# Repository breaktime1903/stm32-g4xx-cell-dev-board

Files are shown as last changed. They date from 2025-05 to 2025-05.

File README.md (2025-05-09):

# STM32G4xx Cell DevBoard开发板

一时兴起无聊做的STM32G4开发板（因为G474/G431两个芯片pin2pin兼容所以在上面加了个丝印区分，应该是通用的吧），称之为Cell是因为这玩意确实比较小巧，目前功能如下：

- 25MHz HSE晶振，32.768KHz LSE晶振
- USB Type-C接口（占用PA11，PA12）
- 0.91寸SSD1306 128x32 OLED显示屏，OLED使用PB8（SCL），PB9（SDA）作为引脚，而PB8与BOOT0复用，使用前需要在STM32CubeProgrammer修改Option Bytes
- TPS54302降压供电，最高支持28V输入电压，最大电流为2A（受制于电感

后面应该会基于这个板子设计底板。

### 目前已经打样验证，可放心使用

OLED

两块板子

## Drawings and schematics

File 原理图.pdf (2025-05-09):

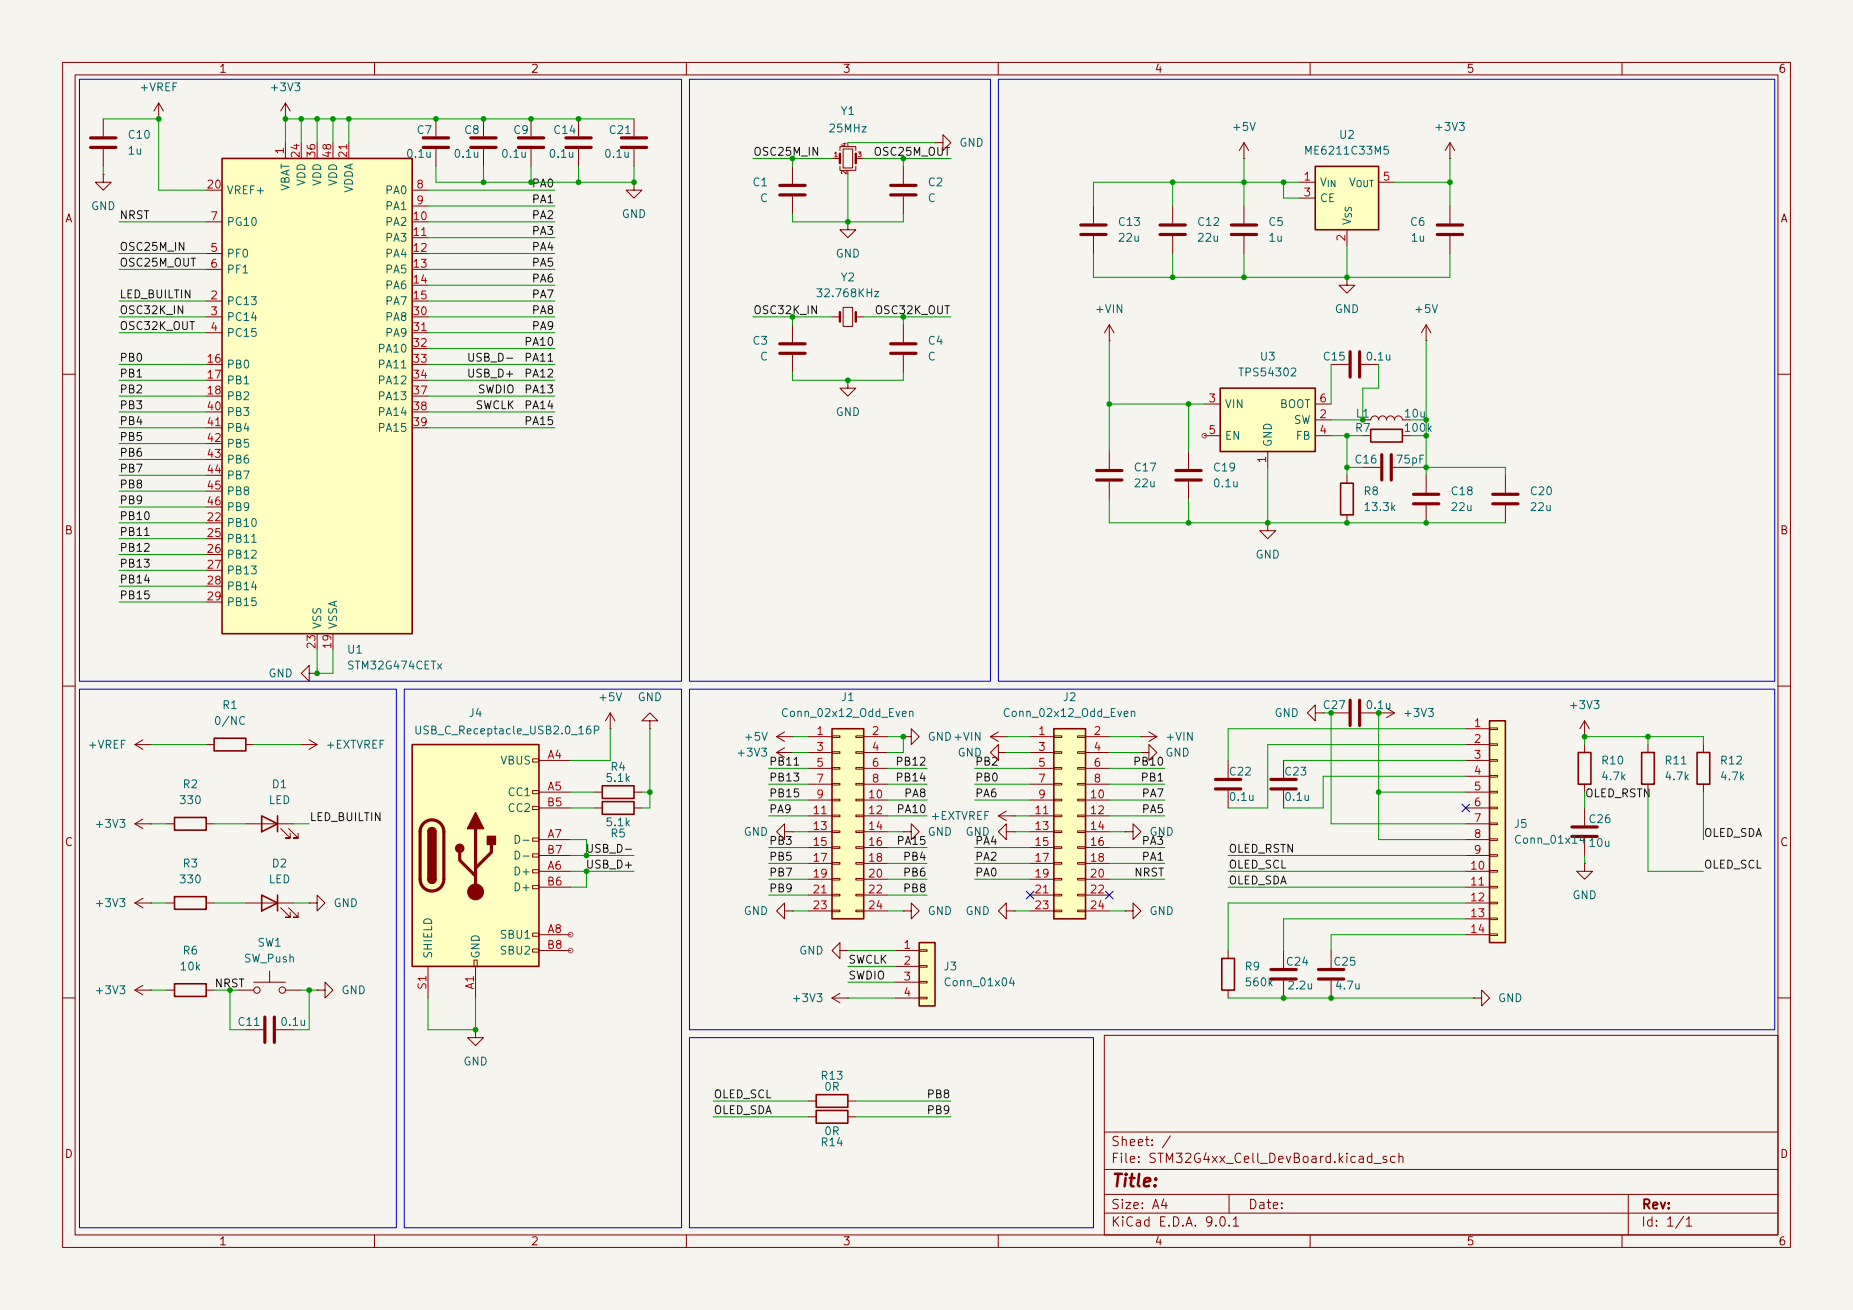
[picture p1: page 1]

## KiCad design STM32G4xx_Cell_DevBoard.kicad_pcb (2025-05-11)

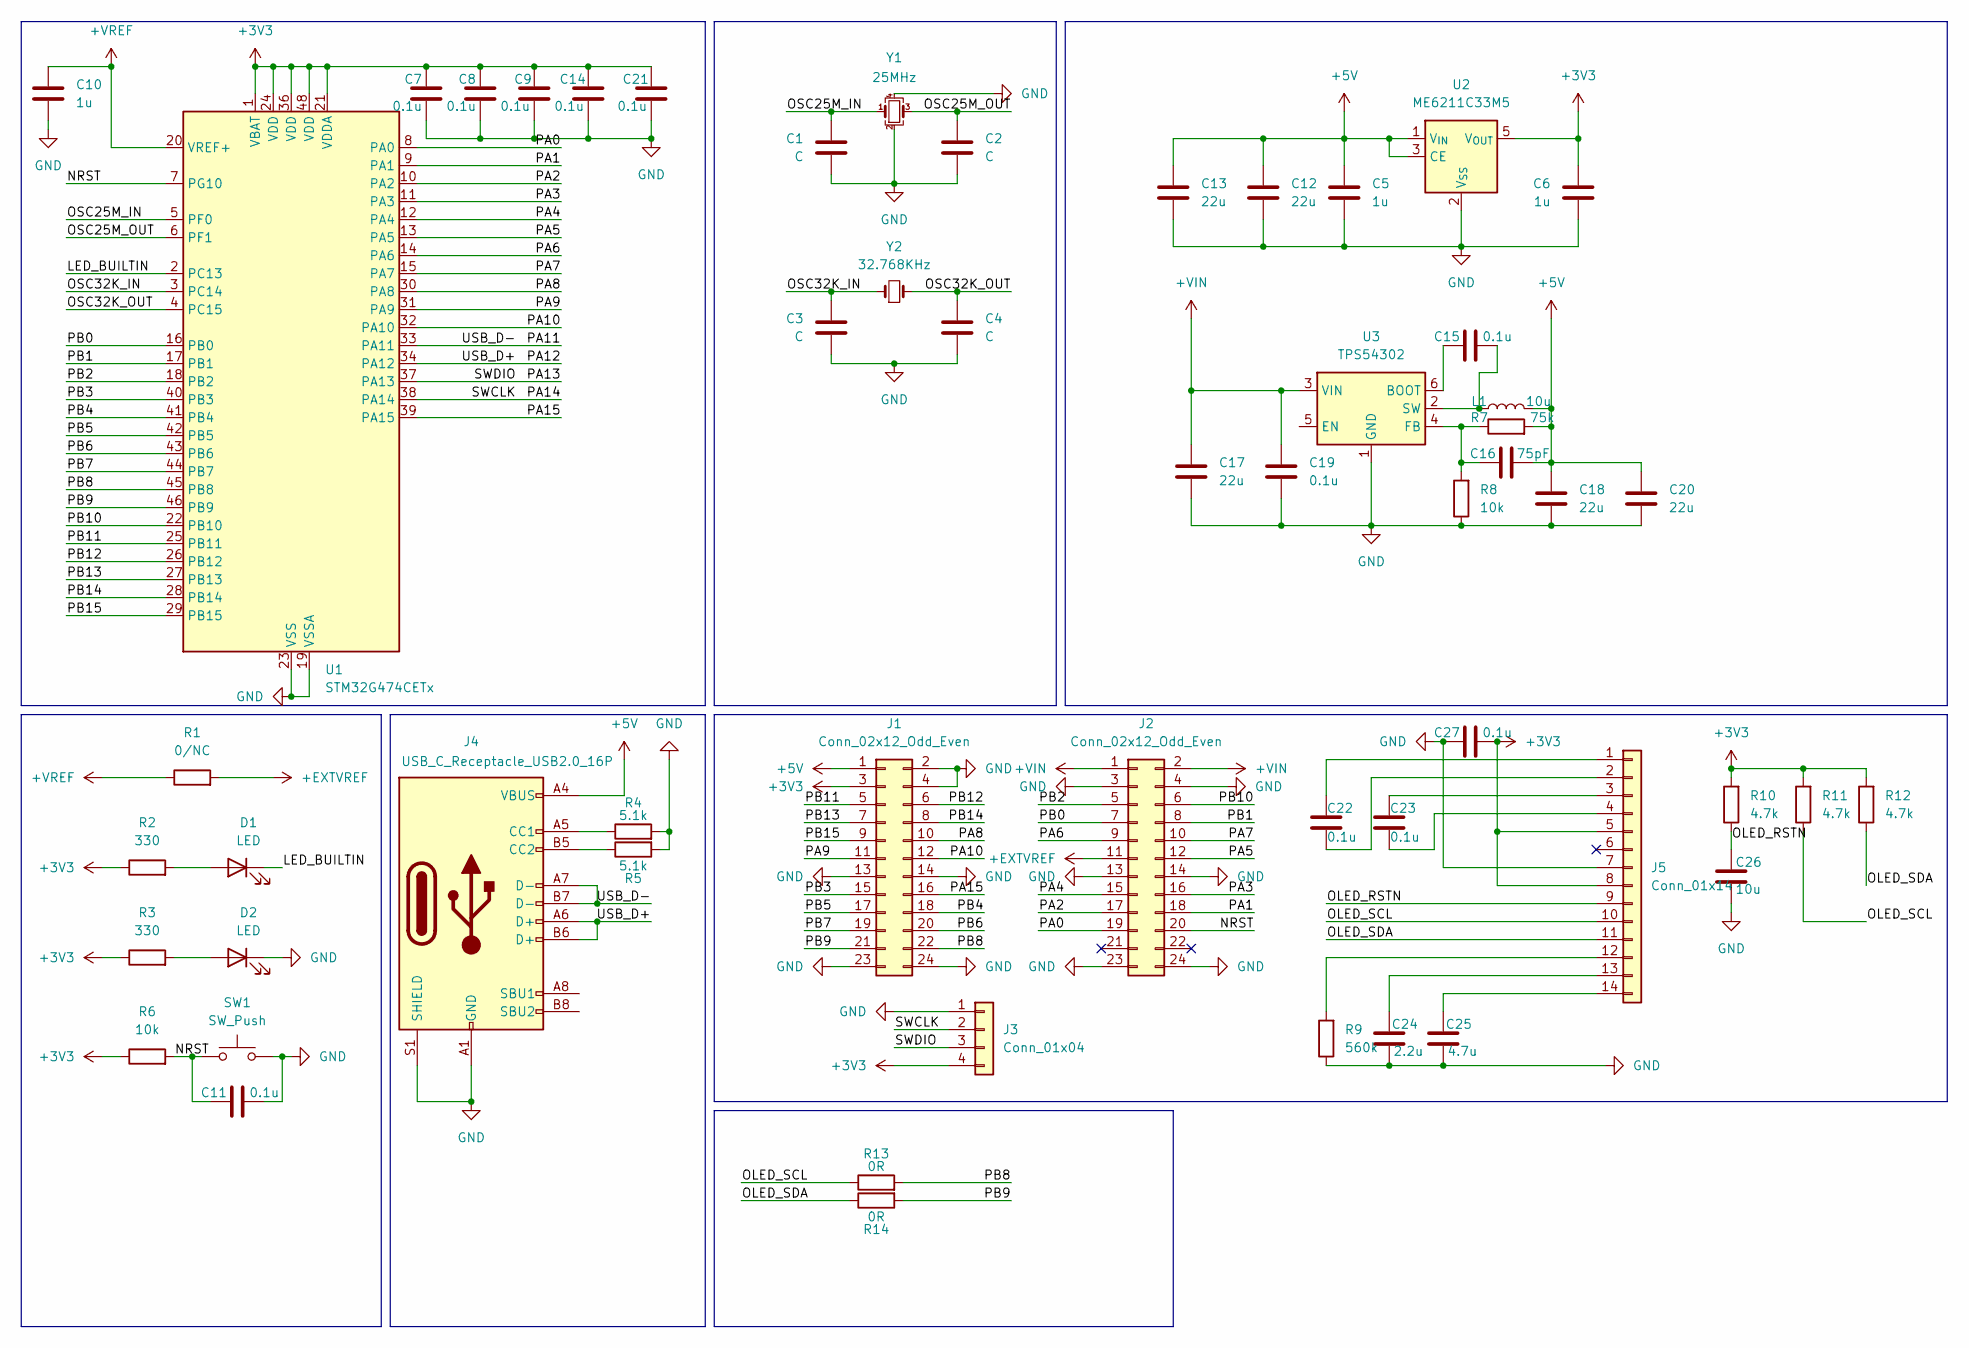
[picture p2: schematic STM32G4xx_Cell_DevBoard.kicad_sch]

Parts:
C1, C2, C3, C4: C; C_0603_1608Metric
C5, C6, C10: 1u; C_0603_1608Metric
C7, C8, C9, C11, C14, C15, C19, C21, C22, C23, C27: 0.1u; C_0603_1608Metric
C12, C13, C17, C18, C20: 22u; C_1206_3216Metric
C16: 75pF; C_0603_1608Metric
C24: 2.2u; C_0603_1608Metric
C25: 4.7u; C_0603_1608Metric
C26: 10u; C_0603_1608Metric
D1, D2: LED; LED_0603_1608Metric
J1, J2: Conn_02x12_Odd_Even; PinHeader_2x12_P2.54mm_Vertical
J3: Conn_01x04; PinHeader_1x04_P2.54mm_Horizontal
J4: USB_C_Receptacle_USB2.0_16P; USB_C_Receptacle_XKB_U262-16XN-4BVC11
J5: Conn_01x14; OLED-SMD_14P-P0.62
L1: 10u; L_Changjiang_FXL0530
R1: 0/NC; R_0603_1608Metric
R2, R3: 330; R_0603_1608Metric
R4, R5: 5.1k; R_0603_1608Metric
R6, R8: 10k; R_0603_1608Metric
R7: 75k; R_0603_1608Metric
R9: 560k; R_0603_1608Metric
R10, R11, R12: 4.7k; R_0603_1608Metric
R13, R14: 0R; R_0603_1608Metric
SW1: SW_Push; 3_4微动开关
U1: STM32G474CETx; LQFP-48_7x7mm_P0.5mm
U2: ME6211C33M5; SOT-23-5
U3: TPS54302; SOT-23-6
Y1: 25MHz; Crystal_SMD_3225-4Pin_3.2x2.5mm
Y2: 32.768KHz; Crystal_SMD_3215-2Pin_3.2x1.5mm

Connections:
+3V3: C6.1, C7.1, C8.1, C9.1, C14.1, C21.1, C27.2, J1.3, J3.4, J5.5, J5.8, R2.1, R3.1, R6.1, R10.2, R11.2, R12.2, U1.1 (VBAT), U1.21 (VDDA), U1.24 (VDD), U1.36 (VDD), U1.48 (VDD), U2.5 (V_{OUT})
+5V: C5.1, C12.1, C13.1, C16.2, C18.1, C20.1, J1.1, J4.A4 (VBUS), J4.A9 (VBUS), J4.B4 (VBUS), J4.B9 (VBUS), L1.2, R7.2, U2.1 (V_{IN}), U2.3 (CE)
+EXTVREF: J2.11, R1.2
+VIN: C17.1, C19.1, J2.1, J2.2, U3.3 (VIN)
+VREF: C10.1, R1.1, U1.20 (VREF+)
/LED_BUILTIN: D1.1 (K), U1.2 (PC13)
/NRST: C11.1, J2.20, R6.2, SW1.1, U1.7 (PG10)
/OLED_RSTN: C26.1, J5.9, R10.1
/OLED_SCL: J5.10, R11.1, R13.1
/OLED_SDA: J5.11, R12.1, R14.1
/OSC25M_IN: C1.1, U1.5 (PF0), Y1.1
/OSC25M_OUT: C2.1, U1.6 (PF1), Y1.3
/OSC32K_IN: C3.1, U1.3 (PC14), Y2.1
/OSC32K_OUT: C4.1, U1.4 (PC15), Y2.2
/PA0: J2.19, U1.8 (PA0)
/PA1: J2.18, U1.9 (PA1)
/PA2: J2.17, U1.10 (PA2)
/PA3: J2.16, U1.11 (PA3)
/PA4: J2.15, U1.12 (PA4)
/PA5: J2.12, U1.13 (PA5)
/PA6: J2.9, U1.14 (PA6)
/PA7: J2.10, U1.15 (PA7)
/PA8: J1.10, U1.30 (PA8)
/PA9: J1.11, U1.31 (PA9)
/PA10: J1.12, U1.32 (PA10)
/PA11: J4.A7 (D-), J4.B7 (D-), U1.33 (PA11)
/PA12: J4.A6 (D+), J4.B6 (D+), U1.34 (PA12)
/PA13: J3.3, U1.37 (PA13)
/PA14: J3.2, U1.38 (PA14)
/PA15: J1.16, U1.39 (PA15)
/PB0: J2.7, U1.16 (PB0)
/PB1: J2.8, U1.17 (PB1)
/PB2: J2.5, U1.18 (PB2)
/PB3: J1.15, U1.40 (PB3)
/PB4: J1.18, U1.41 (PB4)
/PB5: J1.17, U1.42 (PB5)
/PB6: J1.20, U1.43 (PB6)
/PB7: J1.19, U1.44 (PB7)
/PB8: J1.22, R13.2, U1.45 (PB8)
/PB9: J1.21, R14.2, U1.46 (PB9)
/PB10: J2.6, U1.22 (PB10)
/PB11: J1.5, U1.25 (PB11)
/PB12: J1.6, U1.26 (PB12)
/PB13: J1.7, U1.27 (PB13)
/PB14: J1.8, U1.28 (PB14)
/PB15: J1.9, U1.29 (PB15)
GND: C1.2, C2.2, C3.2, C4.2, C5.2, C6.2, C7.2, C8.2, C9.2, C10.2, C11.2, C12.2, C13.2, C14.2, C17.2, C18.2, C19.2, C20.2, C21.2, C24.2, C25.2, C26.2, C27.1, D2.1 (K), J1.2, J1.4, J1.13, J1.14, J1.23, J1.24, J2.3, J2.4, J2.13, J2.14, J2.23, J2.24, J3.1, J4.A1 (GND), J4.A12 (GND), J4.B1 (GND), J4.B12 (GND), J4.S1 (SHIELD), J5.7, R4.2, R5.2, R8.1, R9.1, SW1.2, U1.19 (VSSA), U1.23 (VSS), U1.35 (VSS), U1.47 (VSS), U2.2 (V_{SS}), U3.1 (GND), Y1.2, Y1.4
unnamed: D1.2 (A), R2.2
unnamed: D2.2 (A), R3.2
unnamed: J4.A5 (CC1), R4.1
unnamed: J4.B5 (CC2), R5.1
unnamed: C22.1, J5.1
unnamed: C22.2, J5.2
unnamed: C23.1, J5.3
unnamed: C23.2, J5.4
unnamed: J5.12, R9.2
unnamed: C24.1, J5.13
unnamed: C25.1, J5.14
unnamed: C15.1, U3.6 (BOOT)
unnamed: C16.1, R7.1, R8.2, U3.4 (FB)
unnamed: C15.2, L1.1, U3.2 (SW)

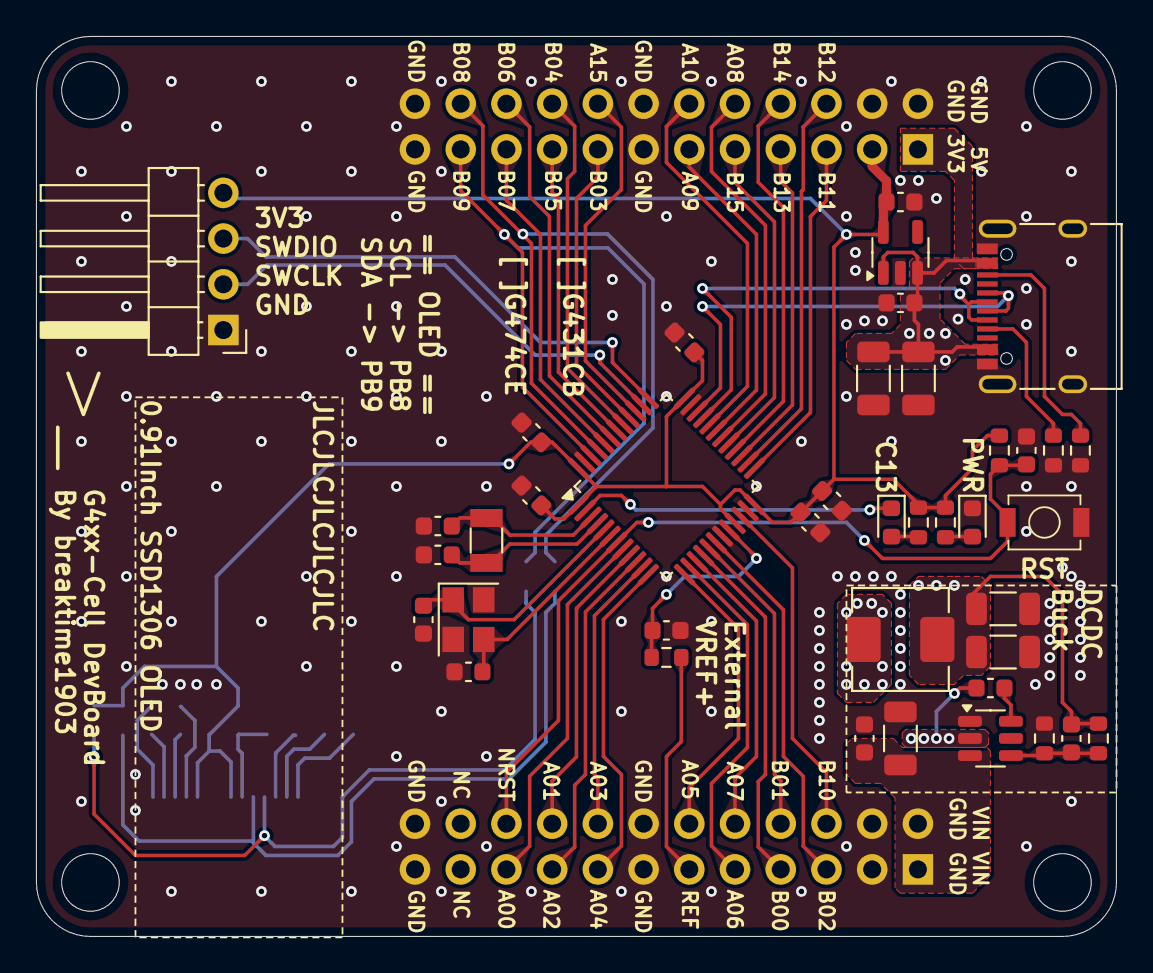
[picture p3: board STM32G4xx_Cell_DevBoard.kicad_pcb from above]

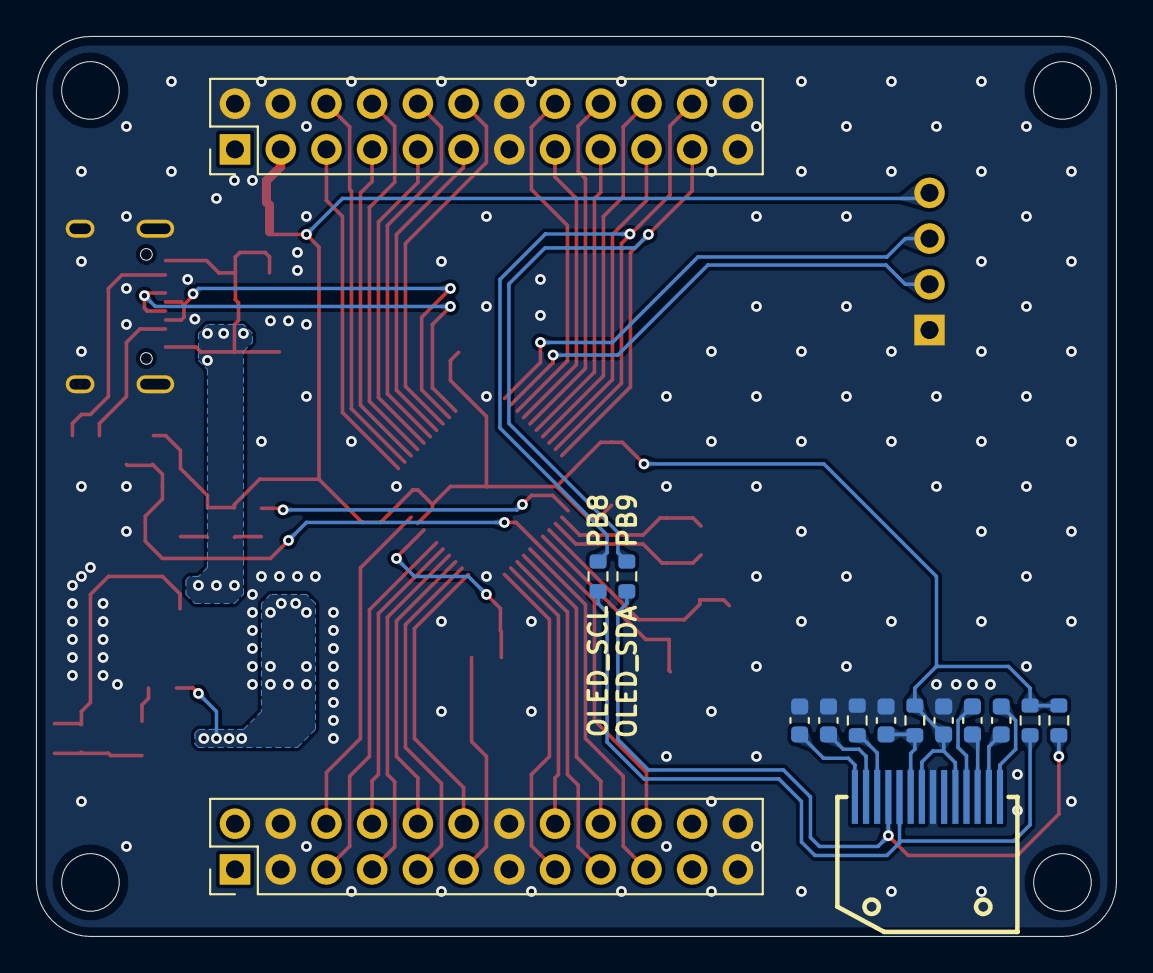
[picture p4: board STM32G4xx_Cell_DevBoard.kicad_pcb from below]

Board: 2 copper layers, 60.0 x 50.0 mm, 55 parts (15 on the bottom side), 61 nets.

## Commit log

2025-05-09 上传文件
    [STM32G4xx_Cell_DevBoard.kicad_pcb, STM32G4xx_Cell_DevBoard.kicad_sch]
2025-05-09 Create LICENSE
    添加LICENSE
2025-05-09 删除重复的工程文件
2025-05-11 添加库文件并修改
    [STM32G4xx_Cell_DevBoard.kicad_pcb, STM32G4xx_Cell_DevBoard.kicad_sch]
2025-05-11 添加自己的库文件（之前忘记添加了）
